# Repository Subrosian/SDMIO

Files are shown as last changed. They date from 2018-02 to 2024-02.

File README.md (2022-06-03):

# Subrosian's Dance Machine IO board
Documentation and source files for a custom IO board for 4 panel dance machines. Unlike most projects in this space, this board will not integrate into existing wiring in a DDR machine. If you are building a machine from scratch or you have a machine that has been completely gutted, this project could be for you. This project involves using a Teensy 3.5 and a Pacdrive to handle button inputs and lighting outputs, with all lighting outputs being RGB light rings (WS2812) and being able to have animations instead of static info coming out of Stepmania.

## Current status

Board is delivered and populated. Next thing to do is test it in my machine.

## Hardware

* 1x Teensy 3.5 (Likely will work with newer Teensys)
* 1x Pacdrive (Screw terminals will need to be removed and pins added)
* 8x 24 LED WS2812 Light Rings (For Pad Lights)
* 4x 12 LED WS2812 Light Rings (For Spotlights)
* 6x Individual LED WS2812s (For buttons) - TODO: Find replacements as previously purchased ones don't work well.
* 2x LED WS2812 light strips (For Subs) - TODO: Find length and density I used

## Hardware Installation

See /documentation folder for hardware stuff

## Software Configuration

I'm currently using and testing against the newest version of Project Outfox but software configuration should be no different than the LumenAR boards for lighting.

In Preferences.ini, make the following changes:
* LightsDriver=PacDrive
* PacDriveLightOrdering=lumenar

## Videos

In progress video showing the new setup: https://www.youtube.com/watch?v=V2iUk6xl10c

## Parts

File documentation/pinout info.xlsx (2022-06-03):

Board Pins | Teensy Pin | Pacdrive Pin | Description
P1-PU | 27 |  | Input Player 1 - Pad Up
P1-PD | 22 |  | Input Player 1 - Pad Down
P1-PL | 28 |  | Input Player 1 - Pad Left
P1-PR | 21 |  | Input Player 1 - Pad Right
P1-BU | 29 |  | Input Player 1 - Console Button Up
P1-BD | 20 |  | Input Player 1 - Console Button Down
P1-BL | 30 |  | Input Player 1 - Console Button Left
P1-BR | 19 |  | Input Player 1 - Console Button Right
P1-BS | 31 |  | Input Player 1 - Console Button Select
BACK | 18 |  | Input - Console Button Back
P2-PU | 32 |  | Input Player 2 - Pad Up
P2-PD | 17 |  | Input Player 2 - Pad Down
P2-PL | 16 |  | Input Player 2 - Pad Left
P2-PR | 15 |  | Input Player 2 - Pad Right
P2-BU | 14 |  | Input Player 2 - Console Button Up
P2-BD | 37 |  | Input Player 2 - Console Button Down
P2-BL | 36 |  | Input Player 2 - Console Button Left
P2-BR | 35 |  | Input Player 2 - Console Button Right
P2-BS | 34 |  | Input Player 2 - Console Button Select
SVC | 33 |  | Input - Console Button Service
AUX | 38 |  | Reserved For Future Use
LED | 39 |  | LED output
TP1 | 23 |  | Reserved For Future Use
TP2 | 13 |  | Internal Board LED
 | 26 | 1 | PAC Player 1 - Pad Left
 | 25 | 2 | PAC Player 1 - Pad Right
 | 24 | 3 | PAC Player 1 - Pad Up
 | 12 | 4 | PAC Player 1 - Pad Down
 | 11 | 5 | PAC Player 2 - Pad Left
 | 10 | 6 | PAC Player 2 - Pad Right
 | 9 | 7 | PAC Player 2 - Pad Up
 | 8 | 8 | PAC Player 2 - Pad Down
 | 7 | 9 | PAC Marquee Upper Left
 | 6 | 10 | PAC Marquee Upper Right
 | 5 | 11 | PAC Marquee Lower Left
 | 4 | 12 | PAC Marquee Lower Right
 | 3 | 13 | PAC Player 1 - Console Buttons
 | 2 | 14 | PAC Player 2 - Console Buttons
 | 1 | 15 | PAC Subwolfers
 | 0 | 16 | Reserved For Future Use

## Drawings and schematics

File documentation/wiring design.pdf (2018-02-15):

# Core Bundle

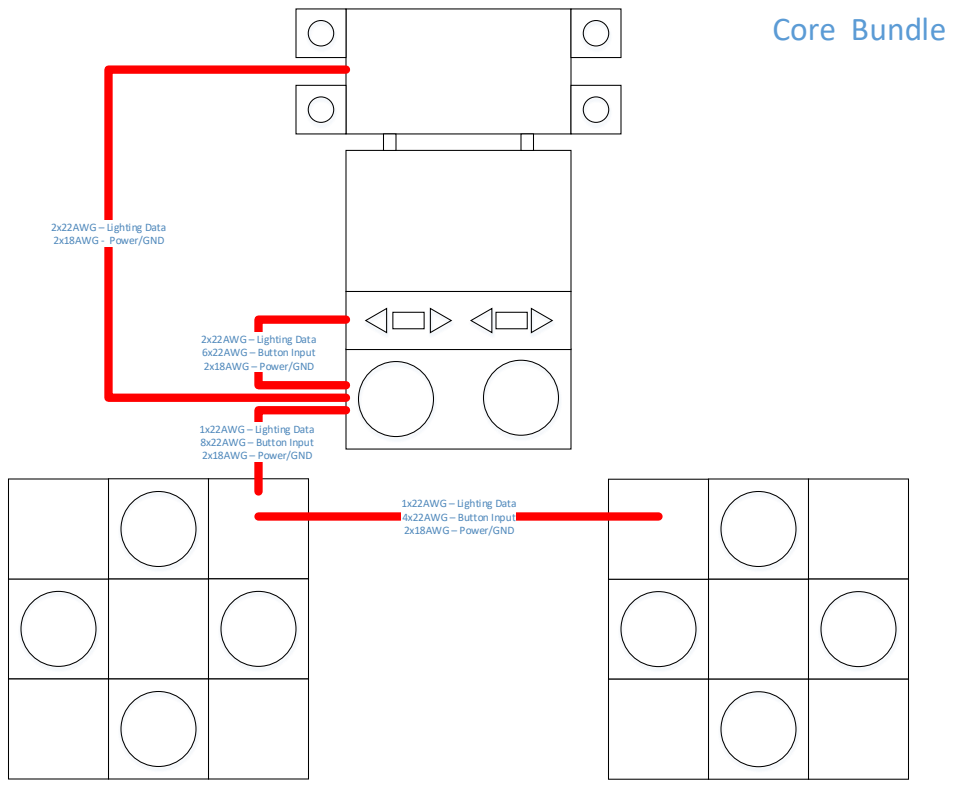
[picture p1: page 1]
1x22AWG – Lighting Data 4x22AWG – Button Input 2x18AWG – Power/GND; 1x22AWG – Lighting Data 8x22AWG – Button Input 2x18AWG – Power/GND; 2x22AWG – Lighting Data 6x22AWG – Button Input 2x18AWG – Power/GND; 2x22AWG – Lighting Data; 2x18AWG -; Power/GND

# LED Data Wire - Logical

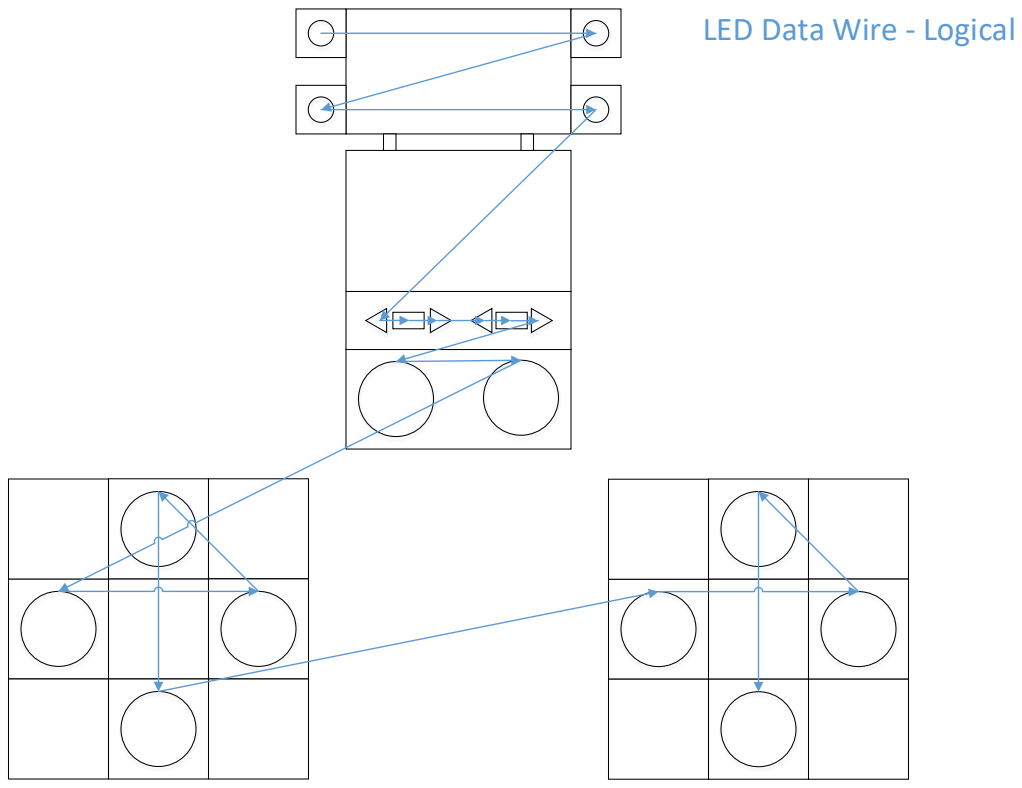
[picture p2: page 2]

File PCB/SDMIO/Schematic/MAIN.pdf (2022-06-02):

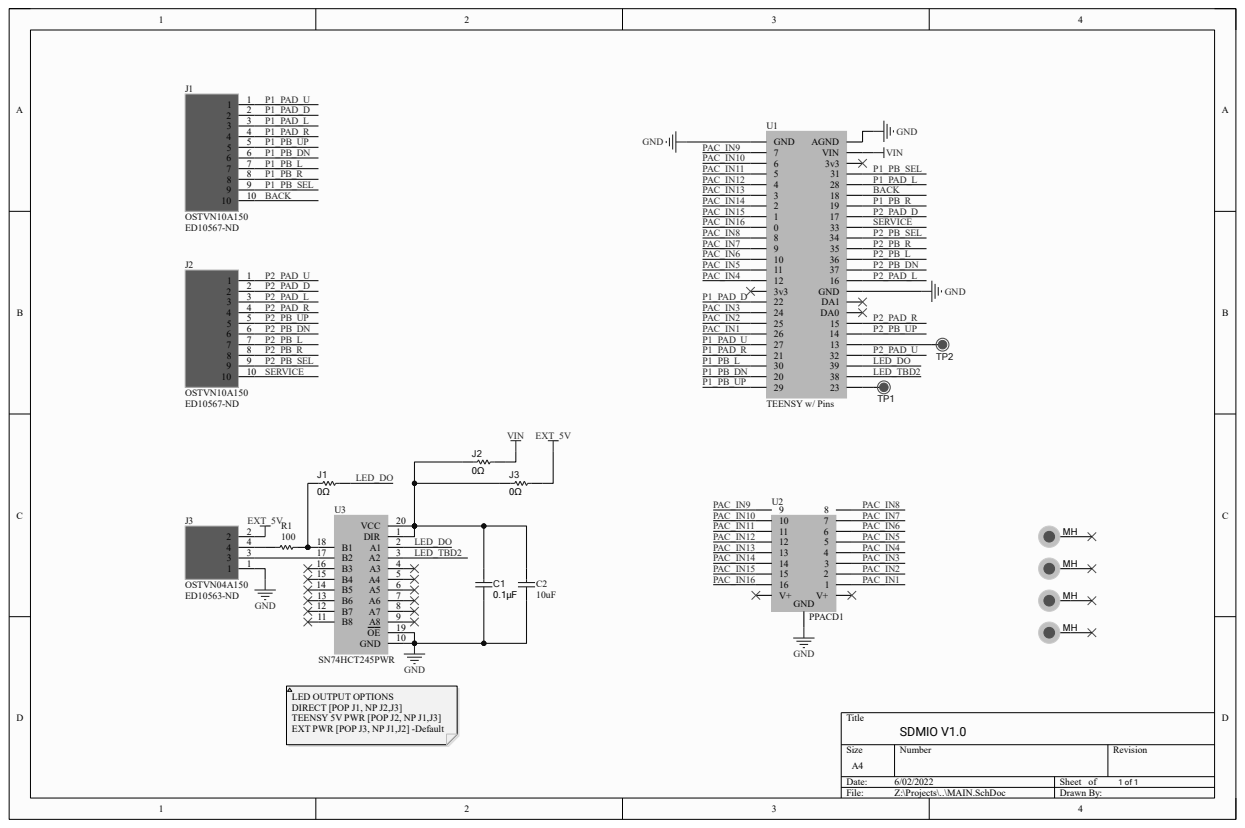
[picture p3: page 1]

LED OUTPUT OPTIONS
DIRECT [POP J1, NP J2,J3]
TEENSY 5V PWR [POP J2, NP J1,J3]
EXT PWR [POP J3, NP J1,J2] -Default

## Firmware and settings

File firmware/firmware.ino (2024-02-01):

//SDMIO 1.1
//Christopher McKinzie (subrosian@gmail.com)
//Board Teensy 3.5
//USB Type Keyboard + Mouse + Joystick
//CPU Speed 120Mhz
//Optimise Faster
//Keyboard Layout English

#include <Adafruit_NeoPixel.h>

#define NUM_LEDS 492
#define DATA_PIN 39
#define LED_REFRESH_RATE 30
//CRGB leds[NUM_LEDS];
Adafruit_NeoPixel leds = Adafruit_NeoPixel(NUM_LEDS, DATA_PIN, NEO_GRB + NEO_KHZ800);




unsigned long lastbutton = 0;
int attractmode = 0;
const int pacInputNum = 16;

#define shutdown_hold_time 5000
unsigned long held_timer;
bool blackout_mode = false;

enum pacInput {
  pacNull,
  pacPad1L,
  pacPad1R,
  pacPad1U,
  pacPad1D,
  pacPad2L,
  pacPad2R,
  pacPad2U,
  pacPad2D,
  pacMarqueeUL,
  pacMarqueeUR,
  pacMarqueeLL,
  pacMarqueeLR,
  pacControl1,
  pacControl2,
  pacSubs,
};

typedef struct {
  byte microInput;
  byte oldState;
  byte onOff;
} pacRef;

pacRef pac[pacInputNum];
const int buttonInputNum = 17;

enum buttonInput {
  buttonNull,
  buttonPad1L,
  buttonPad1R,
  buttonPad1U,
  buttonPad1D,
  buttonPad2L,
  buttonPad2R,
  buttonPad2U,
  buttonPad2D,
  buttonControl1L,
  buttonControl1S,
  buttonControl1R,
  buttonControl2L,
  buttonControl2S,
  buttonControl2R,
  buttonBack,
  buttonConfig
};

typedef struct {
  byte microInput;
  byte oldState;
  byte usbButton;
} buttonRef;

buttonRef button[buttonInputNum];
const int lightOutputNum = 16;

enum lightOutput {
  lightNull,
  lightPad1L,
  lightPad1R,
  lightPad1U,
  lightPad1D,
  lightPad2L,
  lightPad2R,
  lightPad2U,
  lightPad2D,
  lightMarqueeUL,
  lightMarqueeUR,
  lightMarqueeLL,
  lightMarqueeLR,
  lightControl1,
  lightControl2,
  lightSubs,
};

typedef struct {
  int16_t firstLed;
  int16_t numLeds;
  uint32_t fill_color;
  byte oldState;
  byte onOff;
} lightRef;

lightRef light[lightOutputNum];
const int ledPin = 13;
int randomNumber;

void setup() {
  //FastLED.addLeds<WS2811, DATA_PIN, RGB>(leds, NUM_LEDS);

  pac[pacPad1L].microInput = 26;
  pac[pacPad1R].microInput = 25;
  pac[pacPad1U].microInput = 24;
  pac[pacPad1D].microInput = 12;
  pac[pacPad2L].microInput = 11;
  pac[pacPad2R].microInput = 10;
  pac[pacPad2U].microInput = 9;
  pac[pacPad2D].microInput = 8;
  pac[pacMarqueeUL].microInput = 7;
  pac[pacMarqueeUR].microInput = 6;
  pac[pacMarqueeLL].microInput = 5;
  pac[pacMarqueeLR].microInput = 4;
  pac[pacControl1].microInput = 3;
  pac[pacControl2].microInput = 2;
  pac[pacSubs].microInput = 1;

  button[buttonPad1L].microInput = 28;
  button[buttonPad1L].usbButton = 1;
  button[buttonPad1R].microInput = 21;
  button[buttonPad1R].usbButton = 2;
  button[buttonPad1U].microInput = 27;
  button[buttonPad1U].usbButton = 3;
  button[buttonPad1D].microInput = 22;
  button[buttonPad1D].usbButton = 4;
  button[buttonPad2L].microInput = 16;
  button[buttonPad2L].usbButton = 5;
  button[buttonPad2R].microInput = 15;
  button[buttonPad2R].usbButton = 6;
  button[buttonPad2U].microInput = 32;
  button[buttonPad2U].usbButton = 7;
  button[buttonPad2D].microInput = 17;
  button[buttonPad2D].usbButton = 8;
  button[buttonControl1L].microInput = 30;
  button[buttonControl1L].usbButton = 9;
  button[buttonControl1S].microInput = 31;
  button[buttonControl1S].usbButton = 10;
  button[buttonControl1R].microInput = 19;
  button[buttonControl1R].usbButton = 11;
  button[buttonControl2L].microInput = 36;
  button[buttonControl2L].usbButton = 12;
  button[buttonControl2S].microInput = 34;
  button[buttonControl2S].usbButton = 13;
  button[buttonControl2R].microInput = 35;
  button[buttonControl2R].usbButton = 14;
  button[buttonBack].microInput = 18;
  button[buttonBack].usbButton = 15;
  button[buttonConfig].microInput = 33;
  button[buttonConfig].usbButton = 16;

  light[lightMarqueeUL].firstLed = 0;
  light[lightMarqueeUL].numLeds = 12;
  light[lightMarqueeUR].firstLed = 12;
  light[lightMarqueeUR].numLeds = 12;
  light[lightMarqueeLL].firstLed = 24;
  light[lightMarqueeLL].numLeds = 12;
  light[lightMarqueeLR].firstLed = 36;
  light[lightMarqueeLR].numLeds = 12;

  light[pacControl1].firstLed = 350;
  light[pacControl1].numLeds = 1;
  light[pacControl2].firstLed = 351;
  light[pacControl2].numLeds = 1;
  light[pacSubs].firstLed = 54;
  light[pacSubs].numLeds = 104;

  light[lightPad1U].firstLed = 158;
  light[lightPad1U].numLeds = 24;
  light[lightPad1D].firstLed = 182;
  light[lightPad1D].numLeds = 24;
  light[lightPad1L].firstLed = 206;
  light[lightPad1L].numLeds = 24;
  light[lightPad1R].firstLed = 230;
  light[lightPad1R].numLeds = 24;

  light[lightPad2U].firstLed = 254;
  light[lightPad2U].numLeds = 24;
  light[lightPad2D].firstLed = 278;
  light[lightPad2D].numLeds = 24;
  light[lightPad2L].firstLed = 302;
  light[lightPad2L].numLeds = 24;
  light[lightPad2R].firstLed = 326;
  light[lightPad2R].numLeds = 24;

  Serial.begin(9600);
  Serial.println("INFO: Microcontroller Initialized");
  pinMode(ledPin, OUTPUT);
  digitalWrite(ledPin, HIGH);

  //setup all pacinputs as inputs
  for (int counter = 0; counter < pacInputNum; counter++) {
    pinMode(pac[counter].microInput, INPUT_PULLUP);
  }
  //setup all the buttons as inputs
  for (int counter = 0; counter < buttonInputNum; counter++) {
    pinMode(button[counter].microInput, INPUT_PULLUP);
  }
  leds.begin();
}

int reDraw=0;

void fadeLeds(){
  static float fade_amount = 0.60-(1.0/LED_REFRESH_RATE); 
  uint8_t r,g,b;
  for(int x=0;x<NUM_LEDS;x++){
    r=(leds.getPixelColor(x) >> 16);
    g=(leds.getPixelColor(x) >> 8);
    b=(leds.getPixelColor(x));
    if(r > 0){
      r = int(r *fade_amount);
    }
    if(g> 0){
      g = int(g *fade_amount);
    }
    if(b > 0){
      b = int(b *fade_amount);
    }
    leds.setPixelColor(x,r,g,b);
  }
}

void HSV_to_RGB(float h, float s, float v, byte *r, byte *g, byte *b)
{
  int i;
  float f,p,q,t;
  h = max(0.0, min(360.0, h));
  s = max(0.0, min(100.0, s));
  v = max(0.0, min(100.0, v));
  s /= 100;
  v /= 100;
  if(s == 0) {
    // Achromatic (grey)
    *r = *g = *b = round(v*255);
    return;
  }
  h /= 60; // sector 0 to 5
  i = floor(h);
  f = h - i; // factorial part of h
  p = v * (1 - s);
  q = v * (1 - s * f);
  t = v * (1 - s * (1 - f));
  switch(i) {
    case 0:
      *r = round(255*v);
      *g = round(255*t);
      *b = round(255*p);
      break;
    case 1:
      *r = round(255*q);
      *g = round(255*v);
      *b = round(255*p);
      break;
    case 2:
      *r = round(255*p);
      *g = round(255*v);
      *b = round(255*t);
      break;
    case 3:
      *r = round(255*p);
      *g = round(255*q);
      *b = round(255*v);
      break;
    case 4:
      *r = round(255*t);
      *g = round(255*p);
      *b = round(255*v);
      break;
    default: // case 5:
      *r = round(255*v);
      *g = round(255*p);
      *b = round(255*q);
    }
}

void loop() {

  //reset redraw value and check for changes
  reDraw=0;
  static bool current_pin_state;
  static uint8_t r,g,b;

  //check all the pacinputs
  for (int counter = 0; counter < pacInputNum; counter++) {

    //if oldstate does NOT !equal new readstate do something
    current_pin_state = digitalRead(pac[counter].microInput);

    //always set pin to untriggered if blackoutmode
    if(blackout_mode){

      switch(counter){
        case pacSubs:
        case pacMarqueeUL:
        case pacMarqueeUR:
        case pacMarqueeLL:
        case pacMarqueeLR:
          current_pin_state = 1;
        break; 
      }

    }

    if (pac[counter].oldState != current_pin_state) {
      //change in input update leds
      reDraw=1;

      pac[counter].oldState = current_pin_state;

      if (!current_pin_state) {

        //r=g=b=0;

        HSV_to_RGB((random(360)/360.0)*360.0,100.0f,50.0f,&r,&g,&b);

        light[counter].fill_color = leds.Color(r,g,b);
        pac[counter].onOff = !current_pin_state;

        for (int16_t ledCounter = light[counter].firstLed; ledCounter < light[counter].firstLed + light[counter].numLeds; ledCounter++) {
          //leds[ledCounter] = CRGB::Black;
          leds.setPixelColor(ledCounter, light[counter].fill_color);
        }        

      }

    }else if(!current_pin_state){//if pac pad button pressed hold color

      switch(counter){
        case pacPad1L:
        case pacPad1R:
        case pacPad1U:
        case pacPad1D:
        case pacPad2L:
        case pacPad2R:
        case pacPad2U:
        case pacPad2D:

          for (int16_t ledCounter = light[counter].firstLed; ledCounter < light[counter].firstLed + light[counter].numLeds; ledCounter++) {
            //leds[ledCounter] = CRGB::Black;
            leds.setPixelColor(ledCounter, light[counter].fill_color);
          }

        break;
      }

    }

  }

  //needs a redraw
  

  static unsigned long last_update;
  
  if(reDraw==1 or last_update<millis()){
    //FastLED.show();
    fadeLeds();
    leds.show();
    reDraw=0;
    last_update=millis()+(1000/LED_REFRESH_RATE);
  }

  //check all the buttons
  for (int counter = 1; counter < buttonInputNum; counter++) {
    //if oldstate does NOT !equal new readstate do something
    if (button[counter].oldState != digitalRead(button[counter].microInput)) {
      button[counter].oldState = digitalRead(button[counter].microInput);

      if(counter==buttonConfig){

        if(!button[counter].oldState){ //if held

          held_timer=millis()+shutdown_hold_time;
          blackout_mode = !blackout_mode;

        }

      }else{

        //send button state to joystick using oposite new oldstate since !(HIGH=1)=0 and !(LOW=0)=1
        Joystick.button(button[counter].usbButton, !button[counter].oldState);
      }

    }

  }

  if(!button[buttonConfig].oldState && held_timer<millis()){ //if held for shutdown time

    Keyboard.press(KEY_SYSTEM_POWER_DOWN);
    Keyboard.release(KEY_SYSTEM_POWER_DOWN);

  }

}

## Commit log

2018-02-15 Added wiring design documents
    Started working on how the cabinet will be wired.
2018-02-24 Lighting Test 2
    Added color and multiple leds per object to lighting test
2018-06-16 Move from FastLED to NeoPixel Library
    Move from FastLED to NeoPixel Library. The FastLED library was having issues with my AliExpress LED rings, but the NeoPixel library seems to work great with them.
    Very rough code for testing purposes.
2021-03-17 Upload current code from machine
2022-05-19 Added PCB files
    [MAIN.SchDoc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]
2022-06-02 pdf schematic added
    pdf schematic added
2022-06-03 remapped micro pins to new board
    [pinout info.xlsx]
2024-01-29 just a bit of project cleanup
    [MAIN.SchDoc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]
2024-01-31 1.1 updated 1) Service Button (disable/enable sub lights and marquee lights by pressing the service button, always default to enable lights on power on)
2024-01-31 fixed shutdown timer operand comparison
    [firmware.ino]
2024-02-01 added led refresh rate fix millis slow down
    [firmware.ino]
